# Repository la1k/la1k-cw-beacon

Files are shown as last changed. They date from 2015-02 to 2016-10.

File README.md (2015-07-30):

LA1K CW beacon project
======================

A 35-4400 MHz CW exciter design on a 75 x 45 mm 4-layer PCB. Will initially be used for a 70 MHz beacon in Norway (with a 25 W PA and an external 10 MHz OCXO), and eventually replace hardware in our existing 2m and 70cm beacons. A serial port is used for configuration of callsign, ramp time, frequency etc.

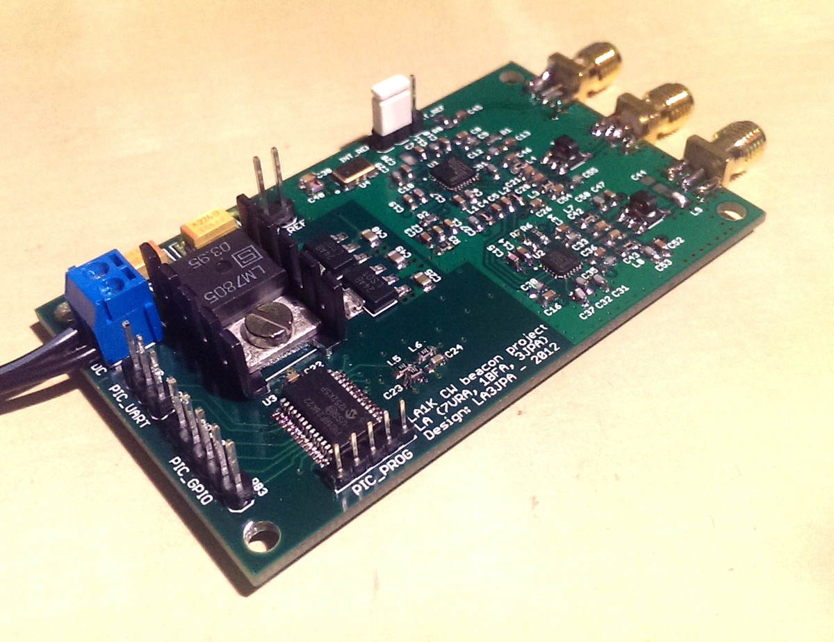
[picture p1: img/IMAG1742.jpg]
First PCB soldered


- **Microcontroller (Microchip PIC18F26K22):** Controls synthesizer, does CW timing, controls VGA gain.
- **Synthesizer (Analog Devices ADF4351):** Fractional-N synthesizer with VCO which generates the RF-signal. Only course control over output power.
- **VGA (Analog Devices ADL5330):** Amplifier with variable gain over a 60 dB span. Controlled by filtered PWM-signal from microcontroller and softens the keying transitions by controlling output power ramping. Also works as a buffer for an external PA.

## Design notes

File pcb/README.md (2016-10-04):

- BOM is located in this folder in CSV and tab-separated formats. 
- Most components have vendor part numbers from Digi-Key.
- Reference oscillator FOX924B, C40 and C38 is typically not inserted if used with external oscillator, as there will be some leakage over the REF_SEL header even without a jumper installed.
- For PCB 1.0, remember to scratch away solder stop mask for U1 and U2 exposed pads.
- Use standard 0.1" / 2.54 mm pitch break-away headers for PIC_GPIO, PIC_UART, REF_SEL and PIC_REF.

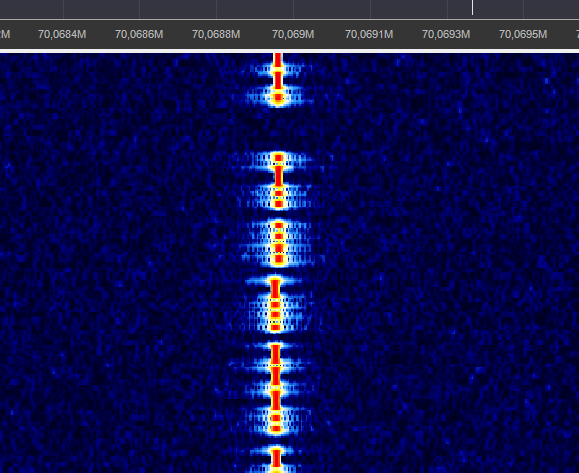
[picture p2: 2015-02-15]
img/ramping_spectrum/11ms.png

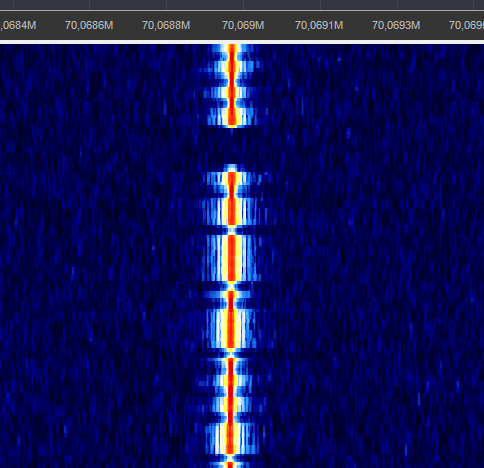
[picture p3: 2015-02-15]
img/ramping_spectrum/22mspng.png

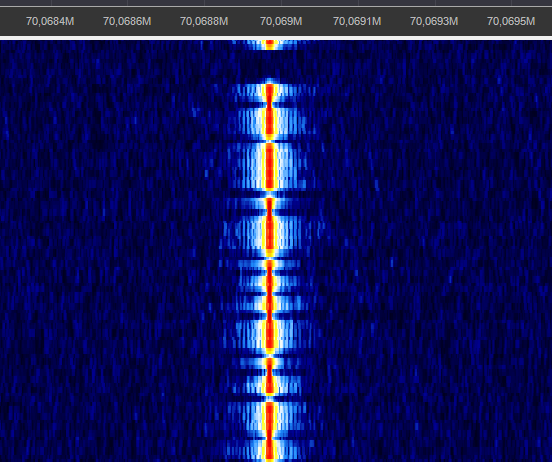
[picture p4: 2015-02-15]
img/ramping_spectrum/11ms_2.png

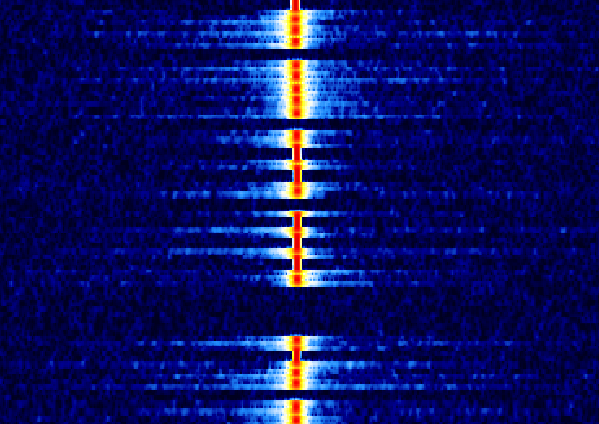
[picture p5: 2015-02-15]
img/ramping_spectrum/hard_on_off.png

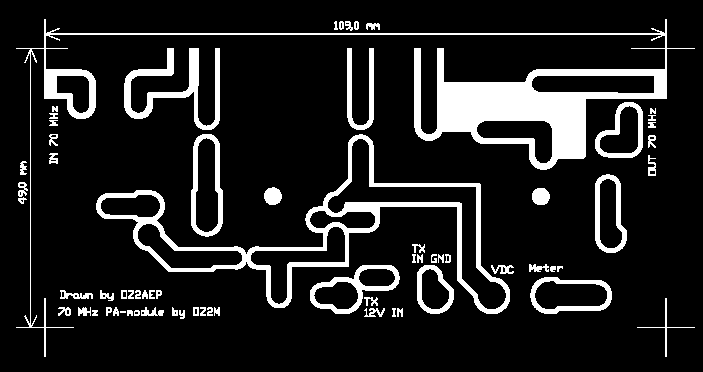
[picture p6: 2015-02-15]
other/70_mhz/pa_design/pmpa_top.png

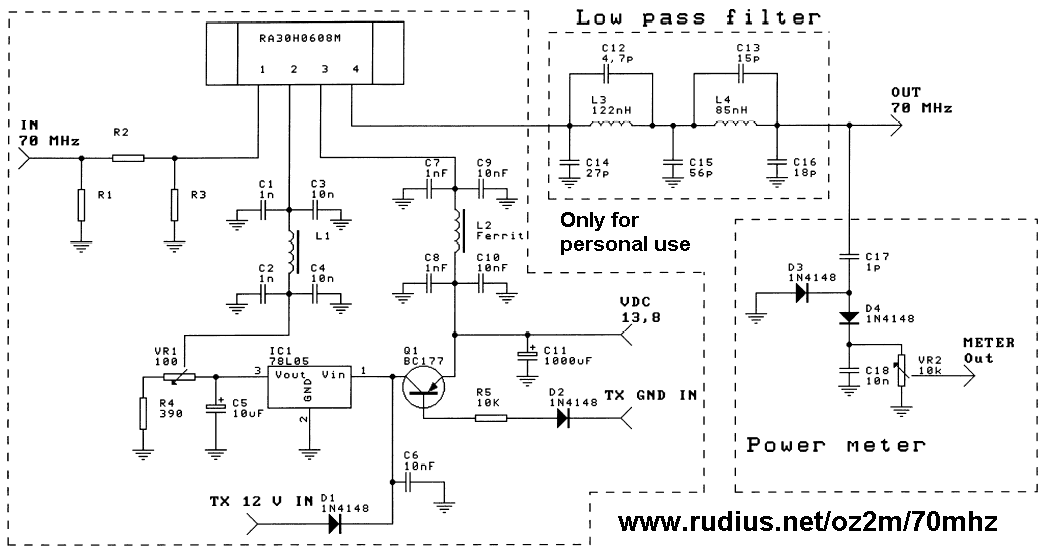
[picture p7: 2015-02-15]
other/70_mhz/pa_design/pmpa_schematic.png

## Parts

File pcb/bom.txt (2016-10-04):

Mfg_PN	Mfg	Vendor_PN	Vendor	Description	Qty-1	Qty-5	Qty-25	Part References	Value
GRM188R71E104KA01D	Murata	490-1524-1-ND	Digikey	CAP CER 0.1UF 25V 10% X7R 0603	20	100	500	"C6, C8, C10, C13, C14, C16, C19, C22, C23, C24, C26, C28, C33, C35, C38, C45, C46, C47, C52, C54"	0.1u
M22-2510505	Harwin	952-1314-ND	Digikey	CONN HEADER 2MM VERT AU 5POS	1	5	25	"PIC_PROG"	1X5_ICSP
MCR03ERTF1001	Rohm	RHM1.00KCFCT-ND	Digikey	RES 1K OHM 1/10W 1% 0603 SMD	1	5	25	"R2"	1k
GRM1885C1H102FA01D	Murata	490-6376-1-ND	Digikey	CAP CER 1000pF 50V 0603	2	10	50	"C42, C43"	1n
GRM1885C1H102FA01D	Murata	490-6376-1-ND	Digikey	CAP CER 1000pF 50V 0603	5	25	125	"C4, C5, C7, C20, C21"	1n
GRM1885C1H272JA01D	Murata	490-3283-1-ND	Digikey	CAP CER 2700pF 50V 0603	1	5	25	"C3"	2.7n
MCR03ERTF3321	Rohm	RHM3.32KCFCT-ND	Digikey	RES 3.32K OHM 1/10W 1% 0603 SMD	2	10	50	"L5, L6"	3.3k
MCR03ERTF3321	Rohm	RHM3.32KCFCT-ND	Digikey	RES 3.32K OHM 1/10W 1% 0603 SMD	1	5	25	"R6"	3.3k
GRM21BR61E475KA12K	Murata	490-6475-1-ND	Digikey	CAP CER 4.7UF 25V 10% X5R 0805	2	10	50	"C25, C48"	4.7u
MCR03ERTF4701	Rohm	RHM4.70KCFCT-ND	Digikey	RES 4.7K OHM 1/10W 1% 0603 SMD	1	5	25	"R1"	4K7
MCR03ERTF1002	Rohm	RHM10.0KCFCT-ND	Digikey	RES 10K OHM 1/10W 1% 0603 SMD	1	5	25	"R7"	10k
GRM1885C1H100FA01D	Murata	490-9713-1-ND	Digikey	CAP CER 10pF 50V 0603	19	95	475	"C9, C11, C12, C15, C17, C18, C27, C29, C30, C31, C32, C34, C36, C37, C40, C50, C51, C53, C55"	10p
TH4C226K016C1400	Vishay	718-1911-1-ND	Digikey	22µF Molded Tantalum Capacitors 16V 2413 (6032 Metric)	2	10	50	"C39, C41"	22u
GRM188R71E473JA01D	Murata	490-11528-1-ND	Digikey	CAP CER 0.047µF 25V 0603	1	5	25	"C2"	47n
ERJ-P06J510V	Panasonic	P51ADCT-ND	Digikey	RES SMD 51 OHM 5% 1/2W 0805	1	5	25	"R8"	50
LQW18ANR10J00D	Murata	490-1179-1-ND	Digikey	INDUCTOR 100nH Unshielded Wirewound Inductor 220mA 680 mOhm Max 0603	2	10	50	"L7, L8"	100n
LQW18ANR10J00D	Murata	490-1179-1-ND	Digikey	INDUCTOR 100nH Unshielded Wirewound Inductor 220mA 680 mOhm Max 0603	4	20	100	"L1, L2, L3, L4"	100n
MCR03ERTF3600	Rohm	RHM360CFCT-ND	Digikey	RES SMD 360 OHM 1% 1/10W 0603	1	5	25	"R3"	360
GRM1885C1H681JA01D	Murata	490-1447-1-ND	Digikey	CAP CER 680pF 50 0603	1	5	25	"C1"	680p
LM7805CT	Fairchild	LM7805CT-ND	Digikey	Linear Voltage Regulator IC Positive Fixed 1 Output 5V 1A TO-220AB	1	5	25	"U5"	7805T
ADF4351BCPZ-RL7	Analog Devices	ADF4351BCPZ-RL7CT-ND	Digikey	IC SYNTH PLL VCO 32LFCSP	1	5	25	"U1"	ADF43510.3_VIA
ADL5330ACPZ-REEL7	Analog Devices	ADL5330ACPZ-REEL7CT-ND	Digikey	RF Amplifier IC	1	5	25	"U2"	ADL5330
CX2156NL	Pulse	553-1499-ND	Digikey	RF Balun 2.3MHz ~ 2.7GHz 1:1 5-SMD	2	10	50	"TR1, TR2"	CX2156NL
PIC18F26K22-I/SS	Microchip Technology	PIC18F26K22-I/SS-ND	Digikey	IC MCU 8BIT 64KB FLASH 28SSOP	1	5	25	"U3"	PIC18F26K20-E/SS
1984617	Phoenix	277-1721-ND	Digikey	2 Position Wire to Board Terminal Block Horizontal with Board 0.138" (3.50mm) Through Hole	1	5	25	"6-12V_DC"	PK5602
SMA-J-P-H-ST-EM1	Samtec	SAM8857-ND	Digikey	SMA Connector Jack, Female Socket 50 Ohm Board Edge, End Launch Solder	3	15	75	"REF_IN, RF_OUT_A, RF_OUT_B"	SMA_CHINA
AP2114H-3.3TRG1	Diodes Inc	AP2114H-3.3TRG1DICT-ND	Digikey	Linear Voltage Regulator IC Positive Fixed 1 Output 3.3V 1A SOT-223	2	10	50	"U6, U7"	V_REG_317SMD
*** ERROR - PART '*' NOT FOUND FOR: "PIC_REF"
*** ERROR - PART '*' NOT FOUND FOR: "PIC_UART, REF_SEL"
*** ERROR - PART '*' NOT FOUND FOR: "PIC_GPIO"
*** ERROR - PART '*' NOT FOUND FOR: "MUXOUT"
*** ERROR - PART '*' NOT FOUND FOR: "C49"
*** ERROR - PART '*' NOT FOUND FOR: "C44"
*** ERROR - PART '*' NOT FOUND FOR: "U4"
*** ERROR - PART '*' NOT FOUND FOR: "L9"

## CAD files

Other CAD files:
firmware/l.obj

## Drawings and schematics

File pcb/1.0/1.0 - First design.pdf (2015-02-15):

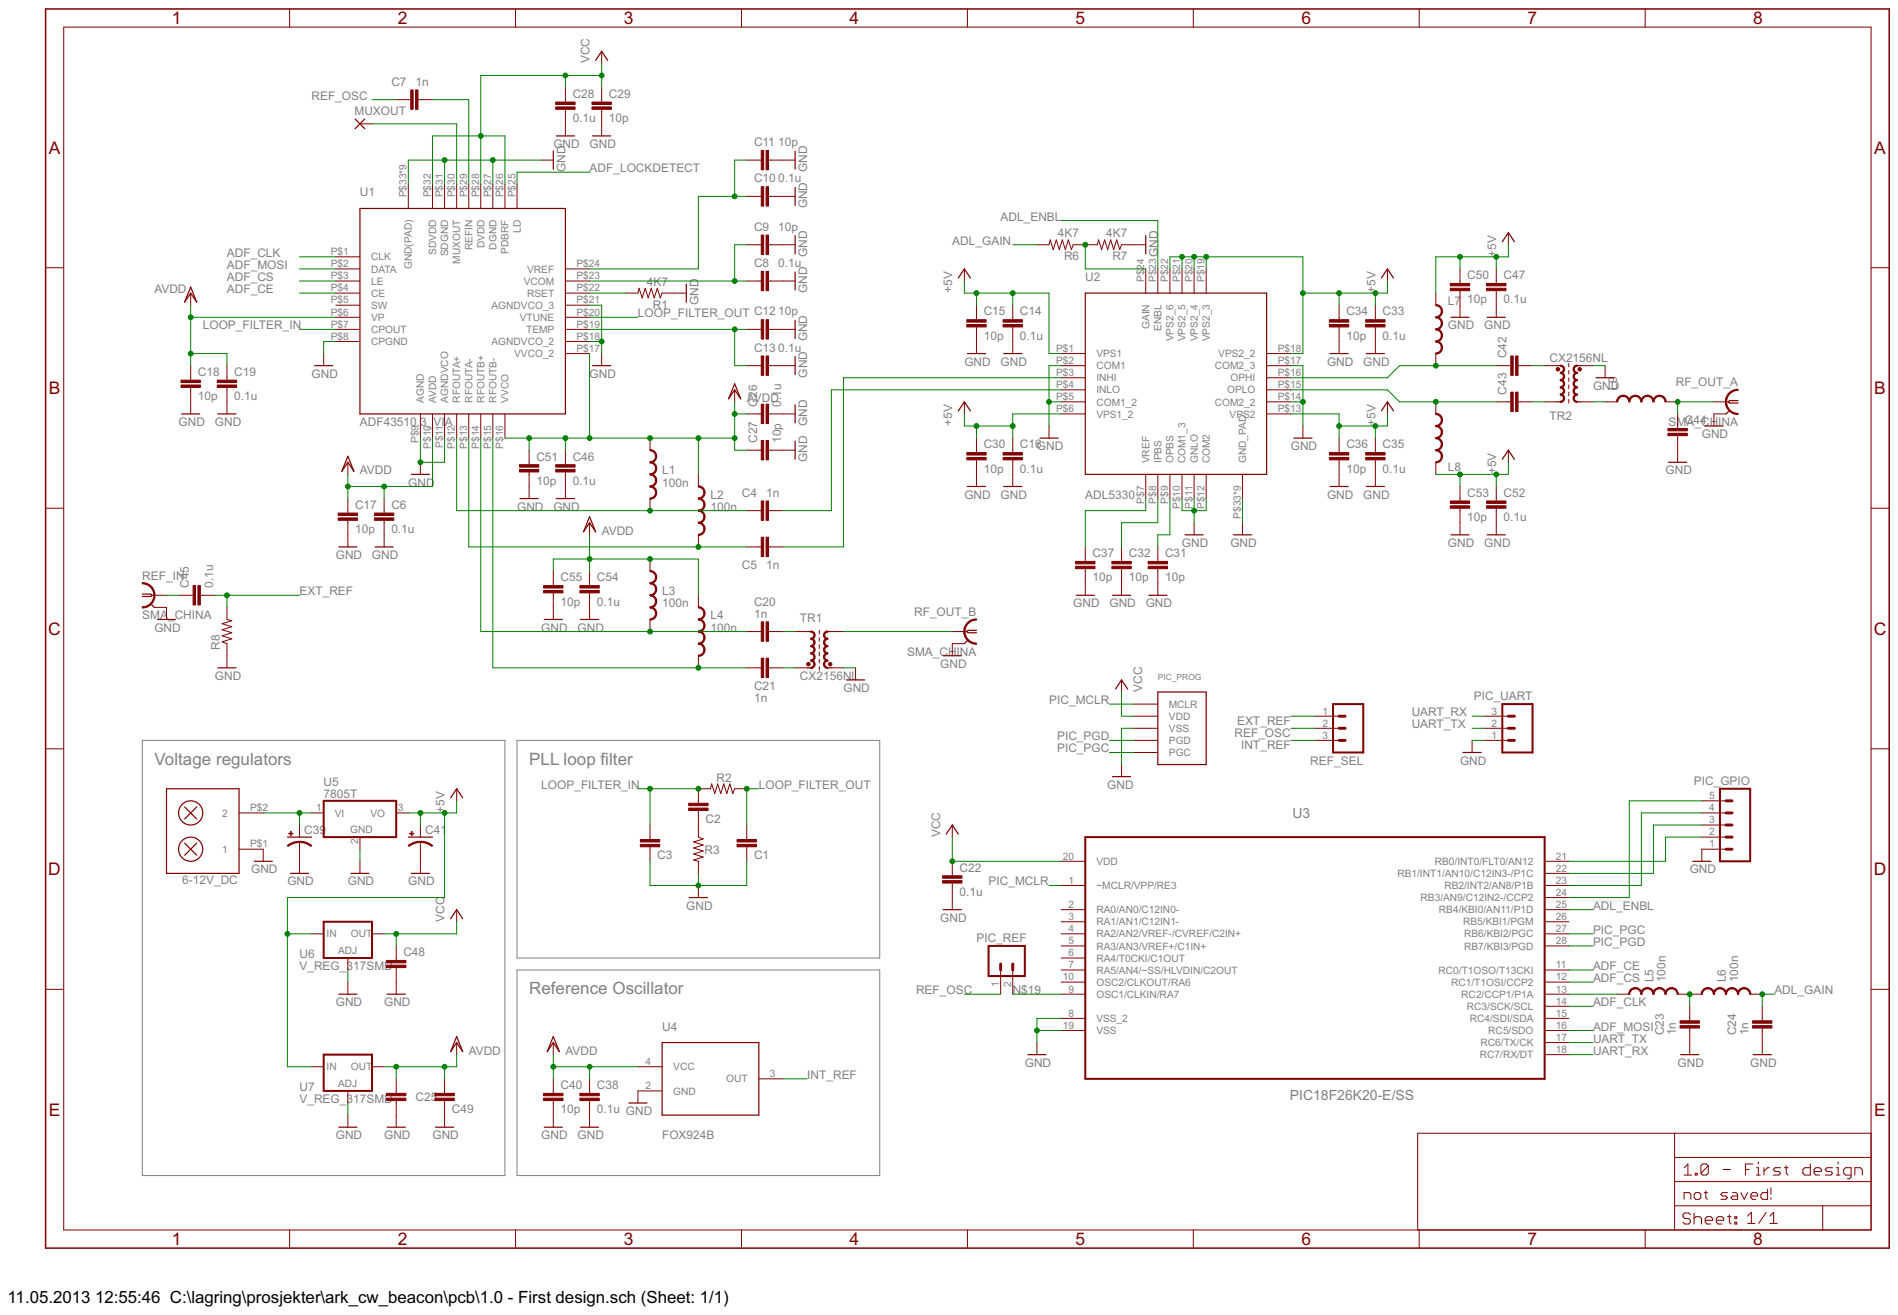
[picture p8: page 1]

GND GND

P$11 RFOUTA+ P$12 RFOUTA- P$13 RFOUTB+ P$14 RFOUTB- P$15 VVCO

11.05.2013 12:55:46 C:\lagring\prosjekter\ark_cw_beacon\pcb\1.0 - First design.sch (Sheet: 1/1)

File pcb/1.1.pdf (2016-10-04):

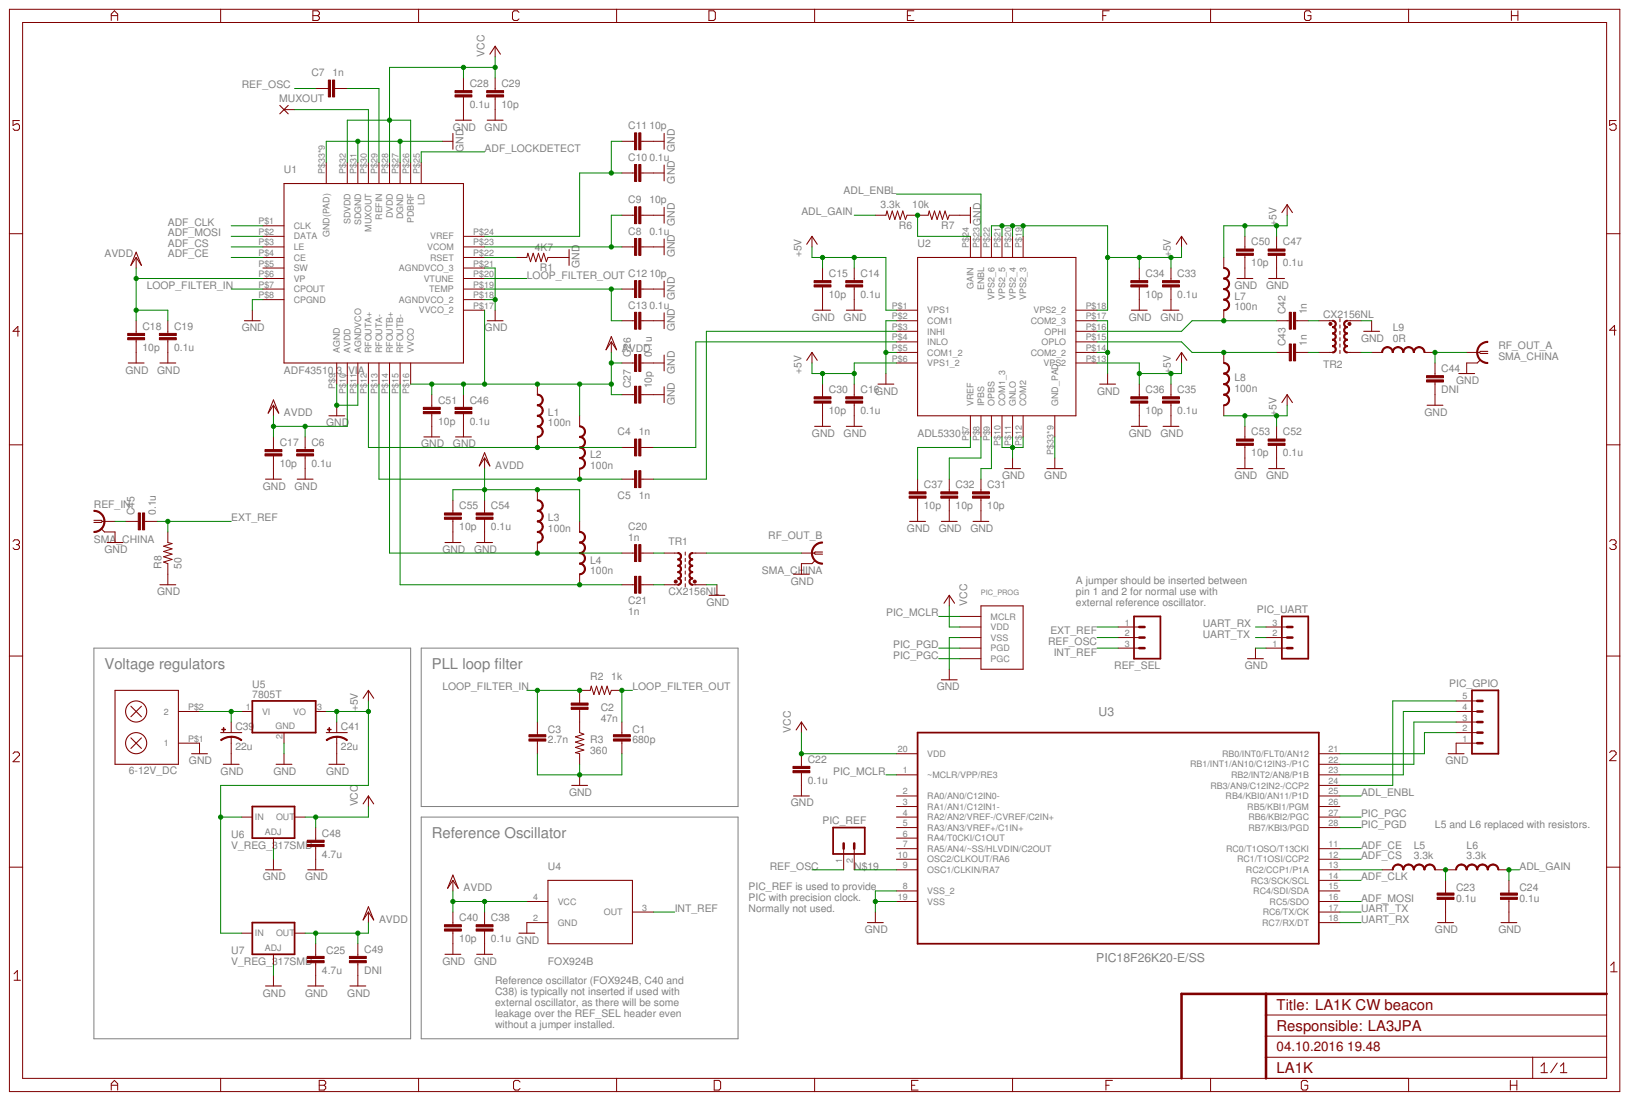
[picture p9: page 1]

GND GND

P$11 RFOUTA+ P$12 RFOUTA- P$13 RFOUTB+ P$14 RFOUTB- P$15 VVCO

A jumper should be inserted between
pin 1 and 2 for normal use with
external reference oscillator.

L5 and L6 replaced with resistors. PIC_REF is used to provide PIC with precision clock. Normally not used.

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

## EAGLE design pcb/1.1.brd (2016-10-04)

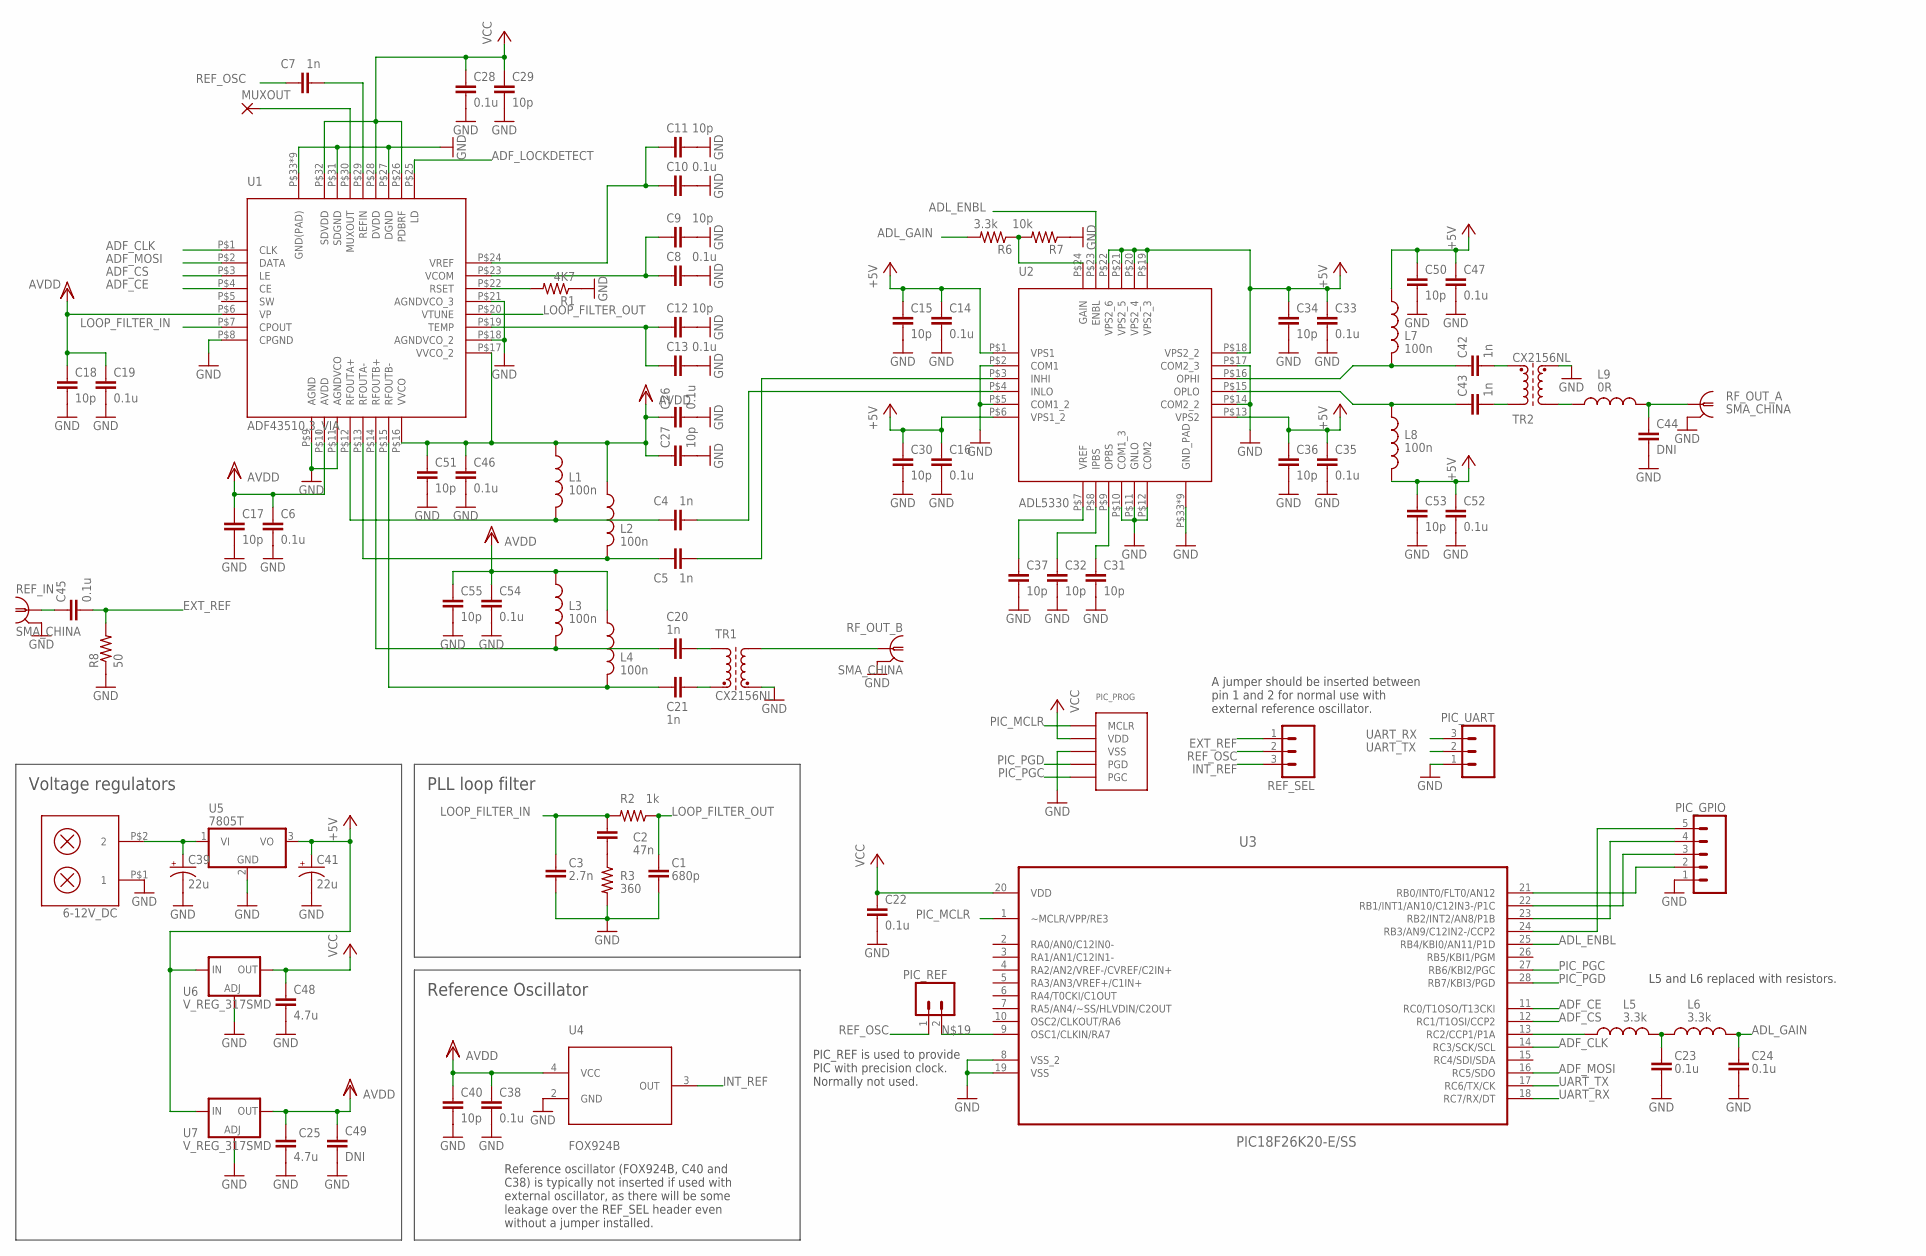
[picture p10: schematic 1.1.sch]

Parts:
6-12V_DC: PK5602; PARTNO 1984617
C1: 680p; 0603-CAP; PARTNO GRM1885C1H681JA01D
C2: 47n; 0603-CAP; PARTNO GRM188R71E473JA01D
C3: 2.7n; 0603-CAP; PARTNO GRM1885C1H272JA01D
C4, C5, C7, C20, C21: 1n; 0603-CAP; PARTNO GRM1885C1H102FA01D
C6, C8, C10, C13, C14, C16, C19, C22, C23, C24, C26, C28, C33, C35, C38, C45, C46, C47, C52, C54: 0.1u; 0603-CAP; PARTNO GRM188R71E104KA01D
C9, C11, C12, C15, C17, C18, C27, C29, C30, C31, C32, C34, C36, C37, C40, C50, C51, C53, C55: 10p; 0603-CAP; PARTNO GRM1885C1H100FA01D
C25, C48: 4.7u; C0805; PARTNO GRM21BR61E475KA12K
C39, C41: 22u; VISHAY_C; PARTNO TH4C226K016C1400
C42, C43: 1n; C0805K; PARTNO GRM1885C1H102FA01D
C44: DNI; C0805K; PARTNO *
C49: DNI; C0805; PARTNO *
L1, L2, L3, L4: 100n; 0603; PARTNO LQW18ANR10J00D
L5, L6: 3.3k; 0603; PARTNO MCR03ERTF3321
L7, L8: 100n; C0805K; PARTNO LQW18ANR10J00D
L9: 0R; C0805K; PARTNO *
MUXOUT: SMD2; SMD1,27-2,54; PARTNO *
PIC_GPIO: M05PTH; 1X05; PARTNO *
PIC_PROG: 1X5_ICSP; 1X5_2MM; PARTNO M22-2510505
PIC_REF: M02PTH; 1X02; PARTNO *
PIC_UART: M03PTH; 1X03; PARTNO *
R1: 4K7; 0603-RES; PARTNO MCR03ERTF4701
R2: 1k; 0603-RES; PARTNO MCR03ERTF1001
R3: 360; 0603-RES; PARTNO MCR03ERTF3600
R6: 3.3k; 0603-RES; PARTNO MCR03ERTF3321
R7: 10k; 0603-RES; PARTNO MCR03ERTF1002
R8: 50; C0805K; PARTNO ERJ-P06J510V
REF_IN: SMA_CHINA; SMA-EDGE; PARTNO SMA-J-P-H-ST-EM1
REF_SEL: M03PTH; 1X03; PARTNO *
RF_OUT_A: SMA_CHINA; SMA-EDGE; PARTNO SMA-J-P-H-ST-EM1
RF_OUT_B: SMA_CHINA; SMA-EDGE; PARTNO SMA-J-P-H-ST-EM1
TR1, TR2: CX2156NL; PARTNO CX2156NL
U1: ADF43510.3_VIA; LFCSP_CP-32-2_.3VIA; PARTNO ADF4351BCPZ-RL7
U2: ADL5330; LFCSP_CP-24-2_.3VIA; PARTNO ADL5330ACPZ-REEL7
U3: PIC18F26K20-E/SS; SOP65P780X200-28N; PARTNO PIC18F26K22-I/SS
U4: FOX924B; PARTNO *
U5: 7805T; TO220H; PARTNO LM7805CT
U6, U7: V_REG_317SMD; SOT223; PARTNO AP2114H-3.3TRG1

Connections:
+5V: C14.1, C15.1, C16.1, C30.1, C33.1, C34.1, C35.1, C36.1, C41.+, C47.1, C50.1, C52.1, C53.1, L7.1, L8.1, U2.P$1 (VPS1), U2.P$6 (VPS1_2), U2.P$13 (VPS2), U2.P$18 (VPS2_2), U2.P$19 (VPS2_3), U2.P$20 (VPS2_4), U2.P$21 (VPS2_5), U2.P$22 (VPS2_6), U5.3 (VO), U6.3 (IN), U7.3 (IN)
ADF_CE: U1.P$4 (CE), U3.11 (RC0/T1OSO/T13CKI)
ADF_CLK: U1.P$1 (CLK), U3.14 (RC3/SCK/SCL)
ADF_CS: U1.P$3 (LE), U3.12 (RC1/T1OSI/CCP2)
ADF_LOCKDETECT: U1.P$25 (LD)
ADF_MOSI: U1.P$2 (DATA), U3.16 (RC5/SDO)
ADF_MUXOUT: MUXOUT.1, U1.P$30 (MUXOUT)
ADL_ENBL: U2.P$23 (ENBL), U3.25 (RB4/KBI0/AN11/P1D)
ADL_GAIN: C24.2, L6.2, R6.2
EXT_REF: C45.2, R8.2, REF_SEL.1
GND: 6-12V_DC.P$1 (1), C1.2, C3.2, C6.2, C8.2, C9.2, C10.2, C11.2, C12.2, C13.2, C14.2, C15.2, C16.2, C17.2, C18.2, C19.2, C22.2, C23.1, C24.1, C25.2, C26.2, C27.2, C28.2, C29.2, C30.2, C31.2, C32.2, C33.2, C34.2, C35.2, C36.2, C37.2, C38.2, C39.-, C40.2, C41.-, C44.2, C46.2, C47.2, C48.2, C49.2, C50.2, C51.2, C52.2, C53.2, C54.2, C55.2, PIC_GPIO.1, PIC_PROG.P$3 (VSS), PIC_UART.1, R1.1, R3.2, R7.1, R8.1, REF_IN.GND@0 (GND), REF_IN.GND@1 (GND), REF_IN.GND@2 (GND), REF_IN.GND@3 (GND), RF_OUT_A.GND@0 (GND), RF_OUT_A.GND@1 (GND), RF_OUT_A.GND@2 (GND), RF_OUT_A.GND@3 (GND), RF_OUT_B.GND@0 (GND), RF_OUT_B.GND@1 (GND), RF_OUT_B.GND@2 (GND), RF_OUT_B.GND@3 (GND), TR1.5 (E2), TR2.5 (E2), U1.P$8 (CPGND), U1.P$9 (AGND), U1.P$11 (AGNDVCO), U1.P$18 (AGNDVCO_2), U1.P$21 (AGNDVCO_3), U1.P$27 (DGND), U1.P$31 (SDGND), U1.P$33 (GND(PAD)), U1.P$34 (GND(PAD)), U1.P$35 (GND(PAD)), U1.P$36 (GND(PAD)), U1.P$37 (GND(PAD)), U1.P$38 (GND(PAD)), U1.P$39 (GND(PAD)), U1.P$40 (GND(PAD)), U1.P$41 (GND(PAD)), U2.P$2 (COM1), U2.P$5 (COM1_2), U2.P$10 (COM1_3), U2.P$11 (GNLO), U2.P$12 (COM2), U2.P$14 (COM2_2), U2.P$17 (COM2_3), U2.P$33 (GND_PAD), U2.P$34 (GND_PAD), U2.P$35 (GND_PAD), U2.P$36 (GND_PAD), U2.P$37 (GND_PAD), U2.P$38 (GND_PAD), U2.P$39 (GND_PAD), U2.P$40 (GND_PAD), U2.P$41 (GND_PAD), U3.8 (VSS_2), U3.19 (VSS), U4.2 (GND), U5.2 (GND), U6.1 (ADJ), U7.1 (ADJ)
INT_REF: REF_SEL.3, U4.3 (OUT)
LOOP_FILTER_IN: C2.1, C3.1, R2.2, U1.P$7 (CPOUT)
LOOP_FILTER_OUT: C1.1, R2.1, U1.P$20 (VTUNE)
unnamed: C5.2, U2.P$3 (INHI)
unnamed: C4.2, U2.P$4 (INLO)
unnamed: C7.2, U1.P$29 (REFIN)
unnamed: L9.1, TR2.4 (A2)
unnamed: C42.1, L7.2, U2.P$16 (OPHI)
unnamed: R1.2, U1.P$22 (RSET)
unnamed: C43.1, L8.2, U2.P$15 (OPLO)
unnamed: C2.2, R3.1
unnamed: C5.1, L2.2, U1.P$13 (RFOUTA-)
unnamed: C4.1, L1.2, U1.P$12 (RFOUTA+)
unnamed: 6-12V_DC.P$2 (2), C39.+, U5.1 (VI)
unnamed: C43.2, TR2.3 (A1)
unnamed: C12.1, C13.1, U1.P$19 (TEMP)
unnamed: C8.1, C9.1, U1.P$23 (VCOM)
unnamed: PIC_GPIO.5, U3.24 (RB3/AN9/C12IN2-/CCP2)
unnamed: C42.2, TR2.1 (E1)
unnamed: PIC_GPIO.4, U3.23 (RB2/INT2/AN8/P1B)
unnamed: C20.1, L3.2, U1.P$14 (RFOUTB+)
unnamed: PIC_REF.2, U3.9 (OSC1/CLKIN/RA7)
unnamed: C10.1, C11.1, U1.P$24 (VREF)
unnamed: C21.1, L4.2, U1.P$15 (RFOUTB-)
unnamed: L5.1, U3.13 (RC2/CCP1/P1A)
unnamed: C21.2, TR1.1 (E1)
unnamed: C23.2, L5.2, L6.1
unnamed: C20.2, TR1.3 (A1)
unnamed: RF_OUT_B.SIG (1), TR1.4 (A2)
unnamed: C37.1, U2.P$7 (VREF)
unnamed: PIC_GPIO.3, U3.22 (RB1/INT1/AN10/C12IN3-/P1C)
unnamed: PIC_GPIO.2, U3.21 (RB0/INT0/FLT0/AN12)
unnamed: R6.1, R7.2, U2.P$24 (GAIN)
unnamed: C45.1, REF_IN.SIG (1)
unnamed: C31.1, U2.P$9 (OPBS)
unnamed: C32.1, U2.P$8 (IPBS)
unnamed: C44.1, L9.2, RF_OUT_A.SIG (1)
PIC_MCLR: PIC_PROG.P$1 (MCLR), U3.1 (~MCLR/VPP/RE3)
PIC_PGC: PIC_PROG.P$5 (PGC), U3.27 (RB6/KBI2/PGC)
PIC_PGD: PIC_PROG.P$4 (PGD), U3.28 (RB7/KBI3/PGD)
REF_OSC: C7.1, PIC_REF.1, REF_SEL.2
UART_RX: PIC_UART.3, U3.18 (RC7/RX/DT)
UART_TX: PIC_UART.2, U3.17 (RC6/TX/CK)
VCC: C22.1, C28.1, C29.1, C48.1, PIC_PROG.P$2 (VDD), U1.P$26 (PDBRF), U1.P$28 (DVDD), U1.P$32 (SDVDD), U3.20 (VDD), U6.2 (OUT)
VDD: C6.1, C17.1, C18.1, C19.1, C25.1, C26.1, C27.1, C38.1, C40.1, C46.1, C49.1, C51.1, C54.1, C55.1, L1.1, L2.1, L3.1, L4.1, U1.P$6 (VP), U1.P$10 (AVDD), U1.P$16 (VVCO), U1.P$17 (VVCO_2), U4.4 (VCC), U7.2 (OUT)

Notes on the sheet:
PLL loop filter
Reference Oscillator
Voltage regulators
L5 and L6 replaced with resistors.
PIC_REF is used to provide PIC with precision clock. Normally not used.
A jumper should be inserted between pin 1 and 2 for normal use with external reference oscillator.
Reference oscillator (FOX924B, C40 and C38) is typically not inserted if used with external oscillator, as there will be some leakage over the REF_SEL header even without a jumper installed.

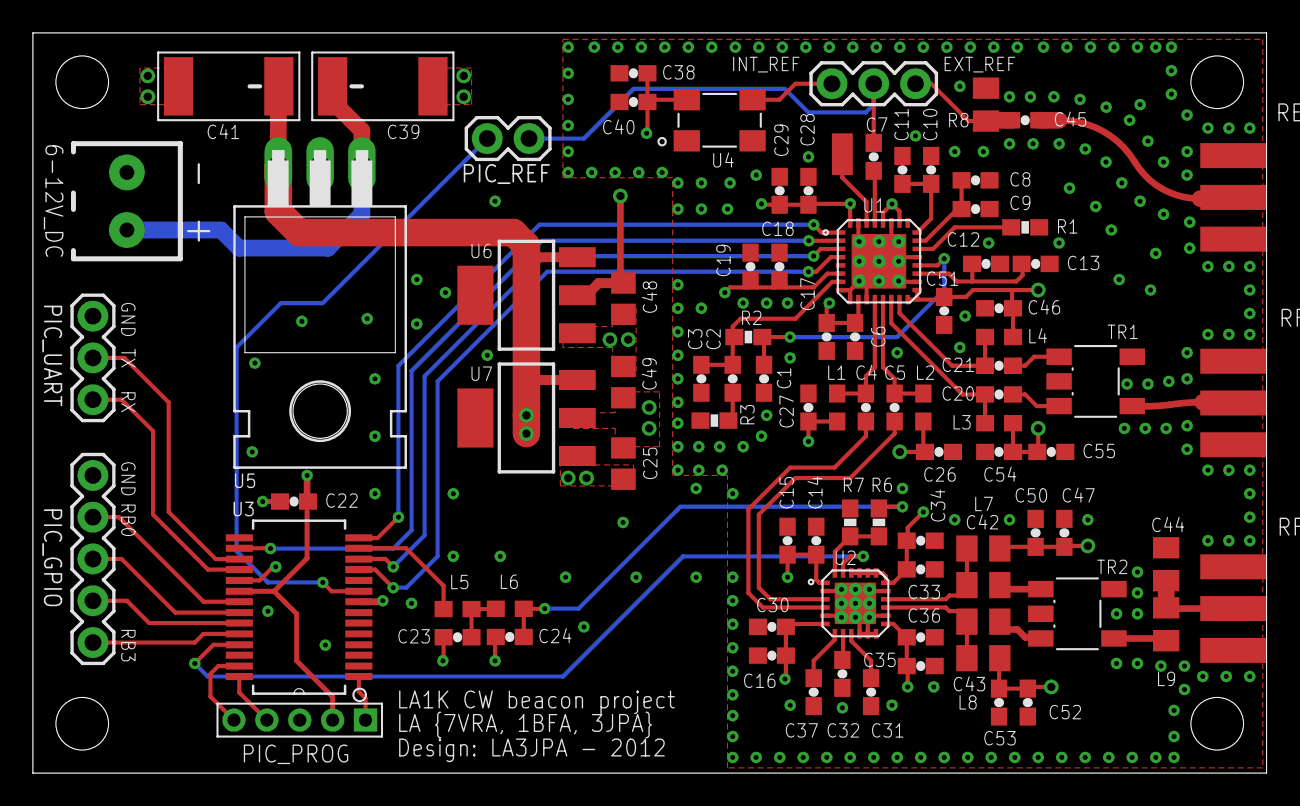
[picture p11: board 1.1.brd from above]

Board: 4 copper layers, 75.0 x 45.0 mm, 89 parts (0 on the bottom side), 55 nets.

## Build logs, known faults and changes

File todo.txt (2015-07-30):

Todo for 70 MHz-fyr:
- Termisk dobbeltsidig teip på PCB

Fra PWM-pinne på uC til kontrollingang på VGA:
  --3k3----------3k3----4k7--
         |    |      |
        3k3  0.1u  0.1u

1.2 / WPM = T_dit (seconds)
1200000 / 64 / WPM = 18750 / WPM = timer ticks
VGA ADL5330 kontrollspenning: 0.1V gir -35db, 1.4V gir 23db (20.7 mv/db), 0 dB ved ca. 0.9V.
Måler 1.386 V ved duty 220 fra uC

PA:
http://rudius.net/oz2m/70mhz/pmpa.htm
Pin = -5.5 dBm (fra radiokort)
4.1 V Vgg: 16.0 dBm -> 21.5 dB gain.
4.9 V Vgg: 21.3 dBm -> 26.8 dB gain.
Fjernet attenuator: 31.2 dBm -> 36.7 dB gain.
70063 KHz. Spurrer på +/- 63 Khz er på -40 dBc
Datablad sier 40 dB gain ved Vgg=5, Vdd=12.5, f=77M, Pin=-5dBm. PA ligger under dette.

Arbeid 120214:
Ut fra ref: 8.9 dBm @ 10 MHz
Ut fra CW-kort: 9.6 dBm på 70,062 MHz (duty 220, adf-pwr 2 - 3.2 dBm med adf-pwr 0), -58.6 dBm på 10 MHz (lekker fra ref.)
Ut fra PA: 43.85 dBm @ carrier, 70 MHz er ca. 50 dB lavere. Strømtrekk er 12 V 5.8 A (69.6 W), idle 3.3 A (39.6 W)
Kjøper høypassfilter mellom ref. og CW-kort.

Arbeid 9/5/15:
Ut fra AUX-utgang: 3.5 dBm
Ut fra RF-utgang: ca. 8.5 dBm (med 1.4 V på Vgain og nivå 3 på synth). For lavt.
4.2 dBm når RF-utgang står på nivå 0.
PA: -26 dBm andreharmonisk når bærebølge er 40 dBm, ref. er ca. -70 dBc
Satte PA tilbake i chassis, og ref. er nå 2 dBm på utgang!

Arbeid 30/05/15:
Annet fyrkort gir bare -2 dBm ut.
12V 5A (60 W) på PA for 44 dBm (25 W) ut
Ble perfekt 43 dBm med power 2 og pwm 215

Arbeid 31/5/15:
70cm PA: 12 V, 3.85 A ved 43 dBm ut.
Skyter i været ved ca. 20 dBm inn. Ved 23 dBm inn gir den 43 dBm ut (og er litt renere enn ved 20 dBm inn).
Bruker Mini-circuits amp. som buffer (-13 dBm fra generator).
Satt ned charge pump fra 2.5 mA 0.63 mA som reduserte spurrer - mulig 
band select clock er r-counter utgang delt på band clk divider
Eksisterende loop-filter 30 KHz 4 mA drive
Lage tnytt 12.5 khz 4mA drive filter
fikk ikke lock med nytt filter! endret PFD til 1 MHz, fikk da lock
Fikk ikke dither til å aktiveres
Med ref. double får man 20 MHz PFD - gir mindre fasestøy
Viste seg at en endring i FW gjorde at frekvens aldri ble satt!

Arbeid 14/6/15:
Bytter ut ADL på første kort. Effekten går drastisk opp:
Duty=200, -4 ut fra ADF, gir 18 dBm ut, 3. harmonisk 2dBm, men MYE rusk rundt grunnfrekvens.
Bytta ut PWM-filter, fra uC: 3.3k, 0.1u, 3.3k, 0.1u, 3.3k, 0.1u+10k, ser bra ut men groms, sannsynligvis fra PLL
Bytta loop-filter til... Hjalp ikke mye. Støy ligger ca. +/- 56 KHz unna.
Optimalisert adf_set_freq i kode

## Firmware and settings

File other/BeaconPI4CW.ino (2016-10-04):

/*
    Simple mixed mode beacon sending PI4, CW callsign and locator and carrier
    for use with the Aurdino Uno platform.
    
    GPS, or another time provider, is not need as it would be in real life.
    To improve timr precission interrupt timing shoudl be implementes.
    
    The LED connected to pin 13 flashed with transmission.

    Environment
    - IDE: Arduino IDE 1.0.1
    - Platform: Arduino Uno LED on pin 13 (built in on Arduino Uno)
    - Hardware: Speaker connected on pin 8

    By Bo, OZ2M - www.rudius.net/oz2m
*/

// Hardware parameters
const int PinSpeaker=8;         // The pin where the speaker is connected
const int PinLED=13;            // Tee pin where the LED is connected

// Software variables
//                     _123456789_123456789_123456789_1234567
const char PI4Chars[]="0123456789ABCDEFGHIJKLMNOPQRSTUVWXYZ /";
const char PI4Vector[]={0,0,1,0,0,1,1,1,1,0,1,0,1,0,1,0,0,1,0,0,0,1,0,0,0,1,1,0,0,1,
                        1,1,1,0,0,1,1,1,1,1,0,0,1,1,0,1,1,1,1,0,1,0,1,1,0,1,1,0,1,0,
                        0,0,0,0,1,1,1,1,1,0,1,0,1,0,0,0,0,0,1,1,1,1,1,0,1,0,0,1,0,0,
                        1,0,1,0,0,0,0,1,0,0,1,1,0,0,0,0,0,1,1,0,0,0,0,1,1,0,0,1,1,1,
                        0,1,1,1,0,1,1,0,1,0,1,0,1,0,0,0,0,1,1,1,0,0,0,0,1,1};
const int PI4MaxInfoLength=8;
const int PI4Symbols=146;       // The number of symbols in the PI4 transmission
int Symbols[PI4Symbols];        // The PI4 symbols
int PI4Tones[4];                // The PI4 tones

int CWCallsign[8];
int CWCallsignLength;
int CWLocator[6];
int CWLocatorLength;

// User variables
char PI4Message[9]="OZ7IGY  ";  // Length of PI4 Message must be 8 charcters. If need pad with spaces
char Callsign[9]="OZ7IGY";      // Max length of callsign is 8 charcters
char Locator[7]="JO55WM";       // Max length of locator is 6 charcters
const int CWTone=800;

int Parity(long int Value)
{
  int Even=0;
  int BitNo;
  for (BitNo=0;BitNo<=31;BitNo++)
    if (((Value >> BitNo) & 0x01) != 0)
      Even=1-Even;

  return Even;
}

void PI4MakeMessage(char *Msg)
{
  int I,J;
  int BitNo;
  
  // Source encoding
  unsigned long long SourceEnc;
  
  SourceEnc=0;
  for (I=0;I<PI4MaxInfoLength;I++)
    SourceEnc=SourceEnc*38+(unsigned long long) (strchr(PI4Chars,Msg[I])-PI4Chars);
  
  // Convolutional Encoding
  const unsigned long Poly1=0xF2D05351;
  const unsigned long Poly2=0xE4613C47;
  unsigned long N=0;
  char ConvEnc[PI4Symbols]={0};

  I=0;
  for (J=0;J<PI4Symbols/2;J++)
  {
    N <<= 1;
    if((SourceEnc & 0x20000000000LLU) != 0)
      N |= 1;
    SourceEnc <<= 1;

    ConvEnc[I++]=Parity(N & Poly1);
    ConvEnc[I++]=Parity(N & Poly2);
  } 

  // Interleaving
  int P=0;
  int R=0;
  int Interleaved[PI4Symbols]={0};
  
  for (I=0;I<=255;I++)
  {
    for (BitNo=0;BitNo<=7;BitNo++)
    {
      if (((I >> BitNo) & 0x01)==0x01)
	R |= 1 << (7-BitNo);
      else
	R &= ~(1Lu << (7-BitNo));
    }

    if ((P<PI4Symbols) && (R<PI4Symbols))
      Interleaved[R]=ConvEnc[P++];
  }

  //  Merge With Sync Vector
  for (I=0;I<PI4Symbols;I++)
    Symbols[I]=PI4Vector[I]+(2*Interleaved[I]);
}

int CharToMorse(char Ch)
{
  const char Letters[]={0x42,0x84,0xA4,0x83,0x01,0x24,0xC3,0x04,0x02,0x74,0xA3,0x44,0xC2,0x82,0xE3,0x64,0xD4,0x43,0x03,0x81,0x23,0x14,0x63,0x94,0xB4,0xC4};
  const char Numbers[]={0x95,0xFD,0x7D,0x3D,0x1D,0x0D,0x05,0x85,0xC5,0xE5,0xF5};
	
  if (Ch==0)
    return(0);                                          // Not a valid morse character
  else
    if (Ch<'A')                                         // Get then Morse pattern
      return(Numbers[Ch-'/']);
    else
      return(Letters[Ch-'A']);
}

void SendMorse(const int *Info, const int Length)
{
  const int CWDotDuration=100;                          // 100 ms = 60 LPM = 12 WPM
  int I,J;
  int Morse;
  int MorseLength;
  
  for (I=0;I<Length;I++)
  {
    Morse=Info[I];
    MorseLength=Morse & 0x07;                           // Bit2 to Bit0 of Morse[I] is the length

    for (J=0;J<MorseLength;J++)
    {
      tone(PinSpeaker,CWTone);  
      digitalWrite(PinLED,HIGH);                        // Turn LED on
      
      if ((Morse & 0x80)==0x80)                         // If MSB 0 = dot, 1 = dash, 
        delay(3*CWDotDuration);                         // It is a dash, so wait 3 dot durations
      else 
        delay(CWDotDuration);                           // It is a dot, so wait 1 dot duration
		  
      noTone(PinSpeaker);  
      digitalWrite(PinLED,LOW);                         // Turn LED off
      delay(CWDotDuration);
      Morse=Morse <<1;                                  // Point to next bit 
    }
    delay(CWDotDuration << 1);                          // Inter morse character pause, 1 dot duration already "gone" so only 2 left
  } 
}

void setup()
{
  int I;
  
  pinMode(PinLED,OUTPUT);                               // Enable LID on pin 13
  digitalWrite(PinLED,LOW);                             // Turn LED off
  
  // Prepare PI4
  PI4MakeMessage(PI4Message);                           // Convert the PI4 message to symbols
  
  PI4Tones[0]=CWTone- (float) 20*12000/2048+0.5;        // Calculate the PI4 tones with K=40
  PI4Tones[1]=CWTone+ (float) 20*12000/2048+0.5;
  PI4Tones[2]=CWTone+ (float) 60*12000/2048+0.5;
  PI4Tones[3]=CWTone+ (float) 100*12000/2048+0.5;
  
  // Prepare CW Callsign
  CWCallsignLength=strlen(Callsign);                    // Find the length of the now encoded CW callsign
  for (I=0;I<CWCallsignLength;I++)                                                                     // Put the EEPROM CW Callsign into the active CW Callsign
    CWCallsign[I]=CharToMorse(Callsign[I]);             // Encode the callsign character
   
  // Prepare CW Locator
  CWLocatorLength=strlen(Locator);                      // Find the length of the now encoded CW callsign
  for (I=0;I<CWLocatorLength;I++)                                                                     // Put the EEPROM CW Callsign into the active CW Callsign
    CWLocator[I]=CharToMorse(Locator[I]);               // Encode the locator character
}

void loop()
{
  int I;
  
  // Wait until 59 s with carrier it real beacon program
  tone(PinSpeaker,CWTone);
  digitalWrite(PinLED,HIGH);                            // Set LED high to indicate carrier
  delay(20000);                                         // Delay "until" sec 59 is reached
  delay(300);                                           // Delay 500 ms incl GPS intrepretation time

  noTone(PinSpeaker);                                   // Speaker off
  digitalWrite(PinLED,LOW);                             // Set LED high to indicate carrier
  delay(500);                                           // Delay between carrier and PI4
  
  // Send PI4 message
  for (I=0;I<PI4Symbols;I++)
  {
    tone(PinSpeaker,PI4Tones[Symbols[I]]);
    digitalWrite(PinLED,!digitalRead(PinLED));          // Toggle LED on/off

    delay(167);                                         // Symbol width 166,667 ms
  }
  noTone(PinSpeaker);                                   // Speaker off
  
  delay(667);                                           // Pause between PI4 message and CW callsign
 
  // Send CW callsign
  SendMorse(CWCallsign,CWCallsignLength);
  delay(500);                                           // Pause between CW callsign and locator
  
  // Send CW locator
  SendMorse(CWLocator,CWLocatorLength);
  delay(500);                                           // Pause between CW locator and carrier
}

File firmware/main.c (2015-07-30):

//**************************************************************//
// LA1K CW beacon - Jon Petter Skagmo, LA3JPA, 2015.            //
// Licensed under LGPL.                                         //
//**************************************************************//

#include <xc.h>
#include <stdint.h>
#include <string.h>
#include <plib.h>

#include "platform.h"
#include "adf.h"
#include "cw.h"
#include "uart.h"
#include "command.h"
#include "config.h"
#include "scheduler.h"
#include "timing.h"

cw_nb_t cw;
void cw_task(void){
	cw_nb_tick(&cw);
}

void button_task(void){
	static uint8_t standby_state;
	if (STANDBY_BTN != standby_state){
		standby_state = STANDBY_BTN;
		if (standby_state){
			uart_puts("MSG: In standby mode\r\n");
			sch_task_disable(SCH_INDEX_CW);
		}
		else{
			uart_puts("MSG: In beacon mode\r\n");
			cw_nb_init(config.cw_string, &cw);
			sch_task_enable(SCH_INDEX_CW);
		}
	}
	
	// If standby mode is on...
	if (standby_state){
		// ...check if "key"-button is pressed (active low) and RF-output is off...
		if ( (!MANUAL_KEY_INV_BTN) && (!adf_common.rf_enable) ) cw_on();
		// ...then check if "key"-button is released and RF-output is on
		else if ( MANUAL_KEY_INV_BTN && adf_common.rf_enable ) cw_off();
	}
}

int main(int argc, char** argv) {
	platform_init();
	pwm_init();
	uart_init(38400);
	timer_init();

	// Initialize main settings
	strcpy(config.cw_string, " LA2UHF JP53EG ");
	config.freq = 432463; // Frequency in KHz, 432463 for LA2UHF
	config.duty = 195; // 0=0V=-40dB gain, 0.9V=0dB, 220=1.4V=23dB
	config.ramp_time = 30;
	cw.carrier_time = 50;
	adf_common.aux_enable = 0;
	adf_common.aux_power = 0;
	adf_common.rf_enable = 1;
	adf_common.rf_power = 0; // -4, -1, 2, 5 dBm - -1 gives the most out of VGA (~10 dBm, other just distorts more)
	
	// Initialize non-blocking morse code generator
	cw_nb_init(config.cw_string, &cw);

	// Initialize RF hardware
	ADL_EN = 1;
	ADF_EN = 1;
	ADF_LE = 0;
	__delay_ms(10);

	// Enable interrupts
	INTCONbits.PEIE = 1;
	INTCONbits.GIE = 1;

	// Run CW-generator at 100 ms intervals
	sch_task_init(SCH_INDEX_CW, 100, &cw_task);			
	sch_task_enable(SCH_INDEX_CW);
	
	// Disable button task if buttons/switches are not connected!
	sch_task_init(SCH_INDEX_BUTTON, 10, &button_task);	
	sch_task_enable(SCH_INDEX_BUTTON);

	adf_calc_freq(config.freq);
	adf_set_all();
	uart_puts("\r\nLA1K CW-beacon HW 0.1, SW 0.11\r\n");
	
	while(1){
		while (uart_inwaiting()) cmd_byte(uart_get());
		sch_tick();
		CLRWDT();
	}

	return 0;
}

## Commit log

2015-07-30 - Fixed scheduler bug where execution stops after 2^31 ms - Added button support (stop keying, key manually) - UART buffer overflow behavior changed (throws away data rather than blocking further exe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
    [LA-Beacons.xls, l.obj]
2016-10-04 Added BOM and updated schematic.
    [1.0 - First design.brd, 1.0 - First design.sch, 1.1.brd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]

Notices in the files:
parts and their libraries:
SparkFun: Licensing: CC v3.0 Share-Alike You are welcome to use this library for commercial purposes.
